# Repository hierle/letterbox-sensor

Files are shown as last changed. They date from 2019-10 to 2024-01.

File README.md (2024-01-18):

# LoRaWan EU868MHz Letterbox Sensor

New version letterbox sensor v2 available here: https://github.com/hierle/letterbox-sensor-v2 :)

sensing letters in your letterbox via IR diode pair, sending out status via LoRaWan/TTN
based on Attiny84, RFM95W, HSDL9100, powered by a CR2032 battery.

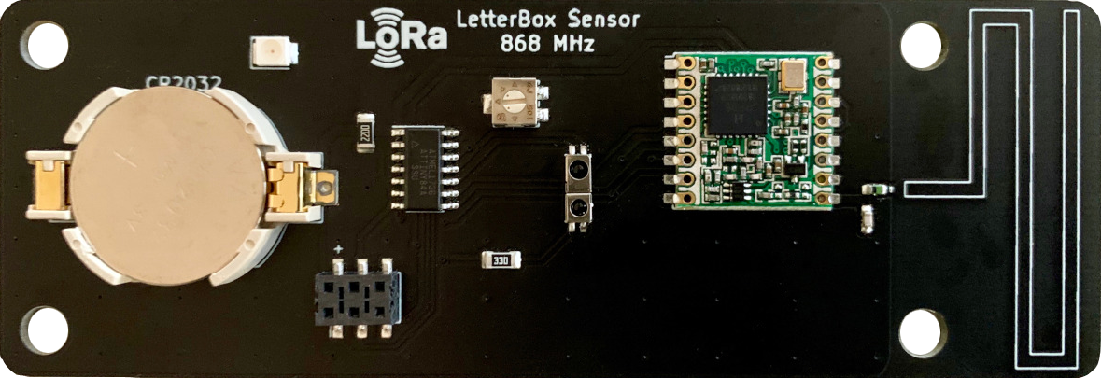
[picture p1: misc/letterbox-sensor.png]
Lora letterbox sensor


This is basically a clone of the heise ct briefkasten sensor project<br> 
https://www.heise.de/ratgeber/IoT-Netz-LoRaWAN-Briefkastensensor-mit-hoher-Reichweite-selber-bauen-4417179.html<br>
https://github.com/jamct/radio-mailbox

Contents:
- ./PCB/ :               kicad PCB files
- ./calibrate/ :         calibration sketch to adjust the poti for letter distance
- ./letterbox_sensor/ :  lora letterbox sensor sketch
- ./misc/ :              payload decoder, sample http integration cgi

Compiled with platformio, hex flashed to attiny with ArduinoISP

Changes:
- created SMD PCB
- onboard 868MHz PCB antenna after TI document http://www.ti.com/lit/an/swra227e/swra227e.pdf
- switched MISO/MOSI lines of RFM95
- Attiny pin renumbering 0...10 -> 10...0
- sensor pin naming changed from 8 -> A2, otherwise no ADC reading
- added basic temperature reading from RFM95
- added sensor raw value, voltage, temperature in lora package

BOM (digikey.de):

|Part number |  Description |
|---|---|
|ATTINY84A-SSUR |  IC MCU 8BIT 14SOIC |
|HSDL-9100-021 |  PROXIMITY SENSOR |
|RFM95W-868S2 |  RF TXRX MODULE |
|3314G-1-105E |  TRIMMER 1M OHM |
|BU2032SM-FH-GTR |  CR2032 COIN CELL HOLDER|
|HLE-103-02-L-DV |  CONN RCPT 6POS |
|AA3528LSECKT/J4 |  LED ORANGE |
|CRGCQ1206F33R |  33R 1206 |
|CRGCQ1206F220R |  220R 1206 |
|LQG18HN1N8S00D |  IND 1.8NH 0603 |
|GRM1885C1H2R7CA01D |  CAP 2.7PF 0603 |

An extended web ui by Peter is available here: https://github.com/pbiering/letterbox-sensor-web

Have fun!

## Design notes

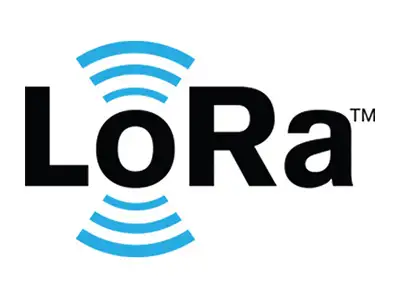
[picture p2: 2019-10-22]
PCB/lora.jpg

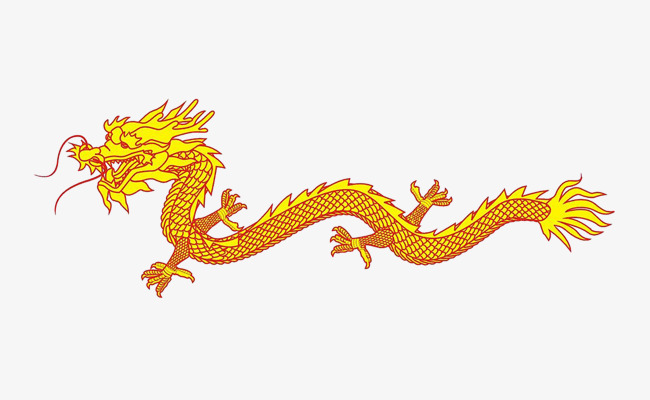
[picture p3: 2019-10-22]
PCB/dragon.jpg

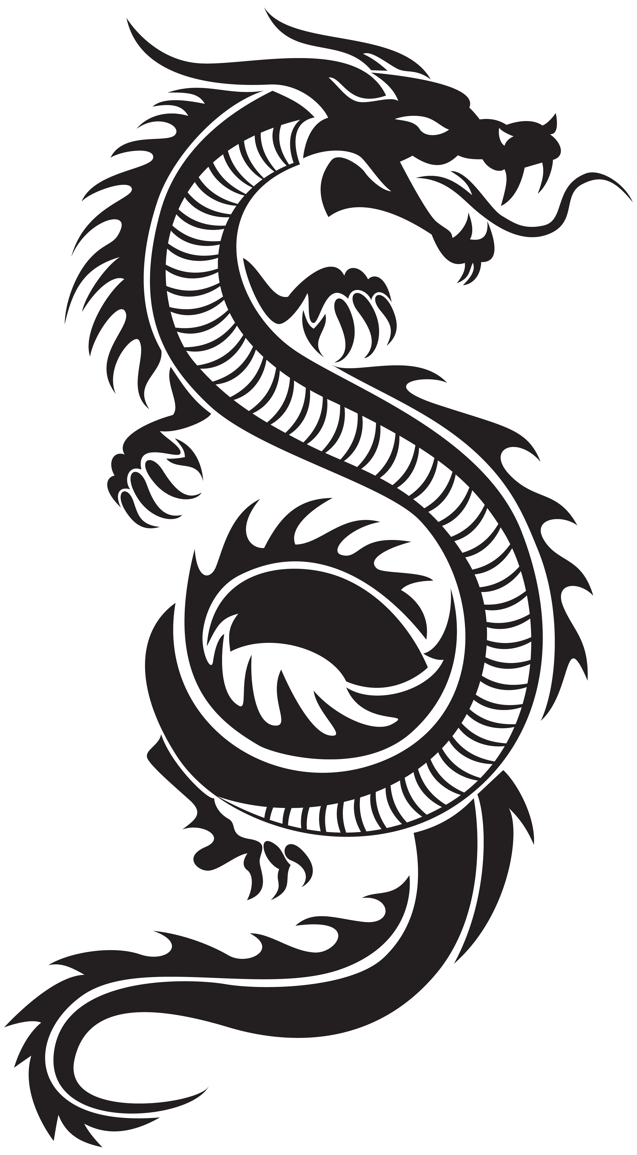
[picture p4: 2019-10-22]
PCB/dragon2.png

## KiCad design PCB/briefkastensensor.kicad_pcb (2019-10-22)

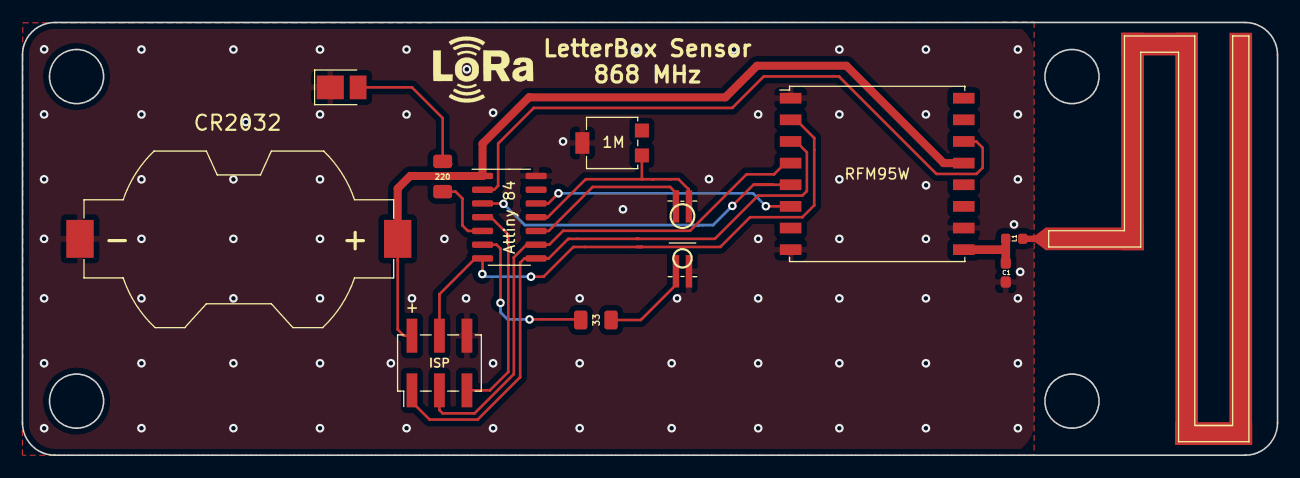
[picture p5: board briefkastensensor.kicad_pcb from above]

Board: 2 copper layers, 116.0 x 40.0 mm, 12 parts (0 on the bottom side), 17 nets.

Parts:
AE1: Antenna; TI-DN024-SL-SHORT
Attiny 84: ATtiny84-20PU; SOIC-14_3.9x8.7mm_P1.27mm
C1: C_Small; C_0603_1608Metric_Pad1.05x0.95mm_HandSolder
CR2032: Conn_01x02; BatteryHolder_Keystone_1058_1x2032
D1: HSDL-9100-021; HSDL-9100
D2: LED; LED_PLCC_2835_Handsoldering
ISP: AVR-ISP-6; PinHeader_2x03_P2.54mm_Vertical_SMD
L1: L; L_0603_1608Metric
R1: 33; R_1206_3216Metric
R2: 220; R_1206_3216Metric
R3: 1M; Potentiometer_Bourns_3314G_Vertical
U2: RFM95W; HOPERF_RFM9XW_SMD

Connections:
+3V3: Attiny 84.1, CR2032.1, ISP.2, U2.13
GND: Attiny 84.14, C1.2, CR2032.2, D1.2, D2.1, ISP.6, R3.2, U2.1, U2.8, U2.10
MISO: Attiny 84.8, ISP.1, U2.3
MOSI: Attiny 84.7, ISP.4, U2.2
unnamed: AE1.1, L1.1
unnamed: C1.1, L1.2, U2.9
unnamed: D1.1, R1.2
unnamed: Attiny 84.11, D1.3, R3.1
unnamed: Attiny 84.10, D1.4
unnamed: D2.2, R2.2
unnamed: Attiny 84.6, R1.1
unnamed: Attiny 84.5, R2.1
unnamed: Attiny 84.2, U2.14
unnamed: Attiny 84.3, U2.5
unnamed: Attiny 84.12, U2.6
RST: Attiny 84.4, ISP.5
SCK: Attiny 84.9, ISP.3, U2.4

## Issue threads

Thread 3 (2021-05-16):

Is there a chance that I can buy this sensor already assembled?

rdmueller, 2021-05-16:
Hey, your PCB looks great!
Do you sell these?

hierle, 2021-11-09:
Actually no, this is not a ready to be used device.
You would also need a TTN account, register the device there, and also flash your keys and firmware to it anyways.

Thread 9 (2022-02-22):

where to order the PCB?

LuisMarek, 2022-02-22:
Hello,

is it possible to order the PCB somewhere or or must everyone find a company themselves that can make this PCB individually? The rest of the parts is not a problem, but the PCB is here probably the obstacle, so at least for me.

Thanks & best regards
Luis

hierle, 2022-02-23:
Hi Luis,

may I ask for your mailing address? ;)

Cheers
Alex
***@***.***>

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

hierle, 2022-02-23:
Hi,

PCBs are not for sale ... but if you drop me a note with your mailing address (e.g. via contact on infotiger.com),  I might have a spare PCB laying around :)

Cheers
Alex

Closed 2022-02-23.

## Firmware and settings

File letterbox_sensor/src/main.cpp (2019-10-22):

#include <attiny.h>
#include "tinySPI.h"
#include "LoRaWAN.h"

//Change Keys in secconfig.h for your TTN application:
#include "secconfig.h"

ATTINY at =  ATTINY();

#include <Arduino.h>

//#define atsleep 16
#define atsleep 1800 // 30min

//ir-led of proximity sensor (invisible)
#define irled 3
// power in for diode in proximity sensor
#define irdiode 7
//adc pin (connect to output of sensor)
#define irsens A2
//
#define statusled 2
//
//#define rfmreset 9


// define a threshold for your mailbox.
//#define THRESHOLD 15
#define THRESHOLD 30

// init RFM95W
#define DIO0 0
#define NSS  1
RFM95 rfm(DIO0,NSS);

LoRaWAN lora = LoRaWAN(rfm);
unsigned int Frame_Counter_Tx = 0x0000;

unsigned int checkLetter();


void setup() {
  at.setSleeptime(atsleep);
  rfm.init();
  lora.setKeys(NwkSkey, AppSkey, DevAddr);
  pinMode(irled, OUTPUT);
  pinMode(statusled, OUTPUT);
  pinMode(irdiode, OUTPUT);
  //pinMode(rfmreset, OUTPUT);
  // blink once
  digitalWrite(statusled, HIGH);
  delay(10);
  digitalWrite(statusled, LOW);
}

void loop() {
  if (at.checkAction()) {
    //uint8_t Data_Length = 0x01;
    //uint8_t Data_Length = 0x06;
    uint8_t Data_Length = 0x07;
    uint8_t Data[Data_Length];
    unsigned int measure = 0;
    measure = checkLetter();

    if(measure > THRESHOLD){
      Data[0] = 0xFF; }
    else {
      Data[0] = 0x00;
    }
   //
   // bat
   unsigned int vol=at.getVoltage();
   Data[1] = (vol & 0xFF);
   Data[2] = ((vol >> 8) & 0xFF);
   // sensor
   Data[3] = ( measure & 0xFF);
   Data[4] = (( measure >> 8) & 0xFF);
   // thresh
   Data[5] = THRESHOLD;
   // temperature, not working yet
   Data[6] = rfm.RFM_Temp();

   // end
   //Data[6] = 0x00;

   //digitalWrite(statusled, HIGH);
   lora.Send_Data(Data, Data_Length, Frame_Counter_Tx);
   Frame_Counter_Tx++;
   //digitalWrite(statusled, LOW);

   //digitalWrite(statusled, HIGH);
   //delay(10);
   //digitalWrite(statusled, LOW);

  }
  //at.setSleeptime(32);
  at.setSleeptime(atsleep);
  at.gotoSleep();
}

//interrupt service routine. Incrementing sleep counter
ISR(WDT_vect)
{
  at.incrCycles();
}

// check ir sensor value
unsigned int checkLetter() {
  digitalWrite(irled,HIGH);
  digitalWrite(irdiode,HIGH);
  unsigned int measure = 0;
  delay(25);
  for(int i = 0 ; i <3 ; i++){
    delay(25);
    measure += analogRead(irsens);
  }
  digitalWrite(irled,LOW);
  digitalWrite(irdiode,LOW);
  measure = measure/3;

  return(measure);
}

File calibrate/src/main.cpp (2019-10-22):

#include <Arduino.h>

//ir-led of proximity sensor (invisible)
//#define irled 7
//
#define irled 3
//
// power in for diode in proximity sensor
//#define irdiode 3
#define irdiode 7
//
//#define irdiode 8
//
//adc pin (connect to output of sensor)
//#define irsens 2
//#define irsens 8
#define irsens A2
//
//#define irsens 7
//
// a simple status LED
//#define statusled 8
#define statusled 2

// define a threshold for your mailbox.
//#define THRESHOLD 15
#define THRESHOLD 15


bool checkLetter();

void setup()
{
  pinMode(irled, OUTPUT);
  pinMode(irdiode, OUTPUT);
  pinMode(statusled, OUTPUT);
  //pinMode(irsens, INPUT);
  digitalWrite(statusled, HIGH);
  delay(500);
  digitalWrite(statusled, LOW);
  delay(500);

  //digitalWrite(irled, HIGH);

}

void loop()
{
  if(checkLetter() == true ){
    digitalWrite(statusled, HIGH);
  }else{
    digitalWrite(statusled, LOW);
  }
  //delay(1000);
  delay(100);


}


bool checkLetter(){
  digitalWrite(irled,HIGH);
  digitalWrite(irdiode,HIGH);
  //delay(100);
  unsigned int measure = 0;
  for(int i = 0 ; i <3 ; i++){
    delay(15);
    measure += analogRead(irsens);
  }
  digitalWrite(irled,LOW);
  digitalWrite(irdiode,LOW);

  measure = measure/3;

  //blink(measure);

  if(measure > THRESHOLD){
    return true;
  }else{
    return false;
  }
}

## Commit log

2019-10-22 letterbox sensor initial version
2019-10-22 added kicad pcb
    [briefkastensensor-B_Cu.gbl, briefkastensensor-B_Mask.gbs, briefkastensensor-B_Paste.gbp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]
2019-10-25 added BOM
2019-10-30 beatified PCB image (thx Hotti)
2019-10-30 beautified PCB image (thx Hotti)
2019-11-04 change color in case lastReceived is above limits
2019-11-11 add query string handling, add additional buttons for switching graphics on/off
2019-11-12 rework button implementation
2019-11-13 sync height of button
2019-11-13 implement auto-reload button
2019-11-14 change colors of rrdRange buttons, use different xgrid for mobile devices
2019-11-14 add support for HTTP_TTN_LETTERBOX_QUERY_STRING (SSI/mod_include), change color of Reload button
2019-11-20 insert dev_id into pictures + timestamp
2019-11-23 add reset button add 2-bit option switch add resistor to trimmer
2019-11-23 change resistor from 10 to 1 k
    [briefkastensensor.sch]
2019-11-23 add comments
    [briefkastensensor.sch]
2019-12-14 add translation support for "de"
2021-10-30 add some trace log
2021-10-30 whitespace fixes
    [briefkastensensor.sch]
2022-02-17 add support for Salted Hash provided by Authen::Passphrase::SaltedDigest in case of Crypt::SaltedHash (only available on EPEL7) is not installed/available
2022-02-18 do not die in case of RRD updates happen too often
2022-02-19 display '*undef* in case a raw data value is missing (.e.g sometimes 'snr' for unknown reason)
2022-02-19 include device hash into module hook 'get_graphics' calls
2022-02-19 add additional graphics 'sensor-zoom-empty', insert sensor threshold line into graphics, code optimization
2022-03-29 disable shift/zoom on mobile, move shift/zoom buttons
2022-03-31 define button height global, align button sizes
2022-03-31 align button sizes
2022-04-02 add support for optional -E|-F <sensor>
2022-04-02 adjust raw content in case of threshold is provided by config (fixes improper WebUI box status display)
2022-04-02 activate change of shift/zoom text color in case not default, remove eol code
2022-04-04 display RRDs for rssi, snr, voltage only in case of "details=on"
2022-04-05 display receivedstatus only in case of "details=on"
2022-04-05 'sensor-zoom-empty' only in case of "details=on"
2022-04-15 display RRDs for 'rssi', 'snr', 'tempC' only in case of "details" != "l1" || "off"
2022-04-22 insert javascript only in case of external captcha service
2022-04-24 delay response also in case of htpasswd file has major issue
2022-04-24 change login window to vertical layout in case of mobile browser detected
2022-04-24 cosmetics related to button size
